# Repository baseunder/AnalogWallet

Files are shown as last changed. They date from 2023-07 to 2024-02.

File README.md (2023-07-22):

# AnalogWallet

## Introduction
Inspired by the online news about a hardware wallet manufacturer that allows private key extraction via closed source firmware i decided to create my own DIY open source crypto wallet.

## Repo
The repository contains the microcontroller source code, 3D STL & Blender files for the case as well as 10MB of random numbers tested with DieHard. Since there is no hardware random number generator on the module I used, i followed the tests of bloc97 
(https://gist.github.com/bloc97/b55f684d17edd8f50df8e918cbc00f94). His 
example uses an analog input with a delay, in my solution I use the 
registers of the Mega32u4 controller to wait for a new ADC conversion. This speeds up the process of generating random numbers a lot.

## Requirements
* Arduino IDE (uECC, EEPROM and SD library)
* Arduino UNO with SD Card reader OR MEGA32u4 SD Card Module (see pictures)
* ISP Programmer (optional and only for production use)
* 3D Printer (optional, for style and electronics protection)

## Crypto
Currently all secp256k1 crypto currencies are supported, this includes for example Bitcoin, Ethereum and of course all Ethereum compatible chains.
The wallet provides plain secp256k1 elliptic curve operations ( https://github.com/kmackay/micro-ecc ):
* Private key generation (random number)
* Public key extraction (on curve)
* Hash signing (for example TX or message signature creation)
* SD Card backup
* SD Card restore

The private key is NEVER stored complete inside the EEPROM or on the SD Card, you always have to provide the correct password to complete the private key. If you enter another password you will end up with another private key that would work too but has no access to your funds.

## Interface
The wallet uses a serial port to communicate with the host system. Inside the py folder you find an example of the protocol used.

## Disclaimer
It should be used only for educational or testing purposes as default 
Arduino boards are not secure by default, their firmware can be updated from the 
computer and this process doesn't require any user interaction. 

## Security
Please upload your sketch with an ISP Programmer and be sure that the Arduino Bootloader is deleted.
Gather your own 10MB of randomness from your device and check the data with some statistic tests (for example https://github.com/nmondal/diehard.c ).
After each "sign" command the device blocks itself and you have to unplug/replug it into your computer.
After each answer from the device there is a 250ms delay inside the communication.

## TODO
Optimize the size of the project so that we can add HMAC-SHA256 key derivation for HD Wallets. Another possible way is to find another USB SD-Card uC board with a bigger flash.
Gather randomness from an Arduino UNO to prove the concept on that platform, this could increase the number of community members.
Generate BTC and ETH addresses from the xpub and make some transactions -> publish the xpub inside this repo so that everyone can try to regenerate the corresponding xpriv (like a bug bounty ;-) ).
User friendly GUI for the communication with the module.

## BadUSB!!
ATTENTION! If you receive such a module DON'T plug it into you Computer because you don't know what program is already loaded inside it. You have to flash the module with an ISP or an ArduinoUNO (Arduino ISP example) the first time. Otherwise the module could act as a virtual Keyboard and harm your privacy or data.

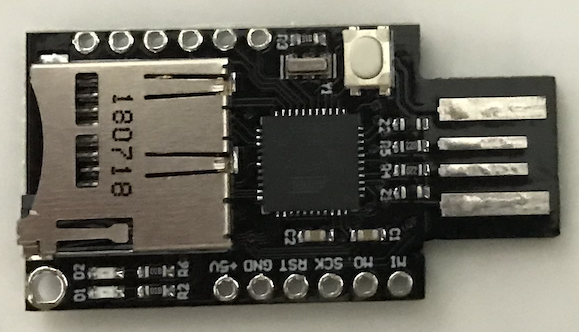
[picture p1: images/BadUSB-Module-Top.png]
BadUSB Module Top

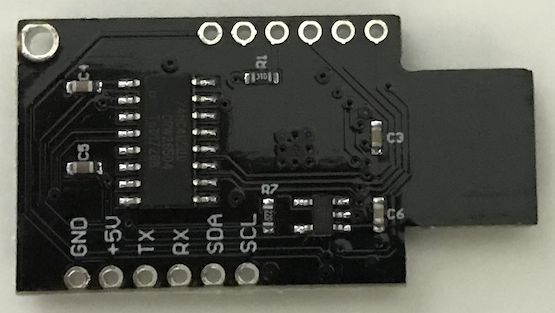
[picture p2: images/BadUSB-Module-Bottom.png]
BadUSB Module Bottom


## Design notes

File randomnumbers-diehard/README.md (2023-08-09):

## Info
For an overview over the "true randomness" topic please visit: https://random.org
## Bad randomness (example)
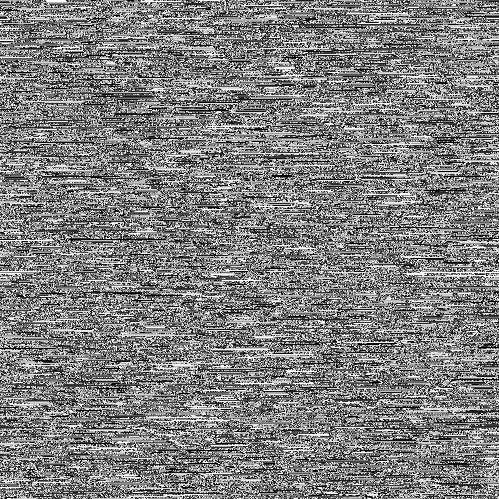
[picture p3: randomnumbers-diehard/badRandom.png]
badRandom randomness picture

## Good randomness (generated with AnalogWallet)
### ATMEGA32U4 Board 1
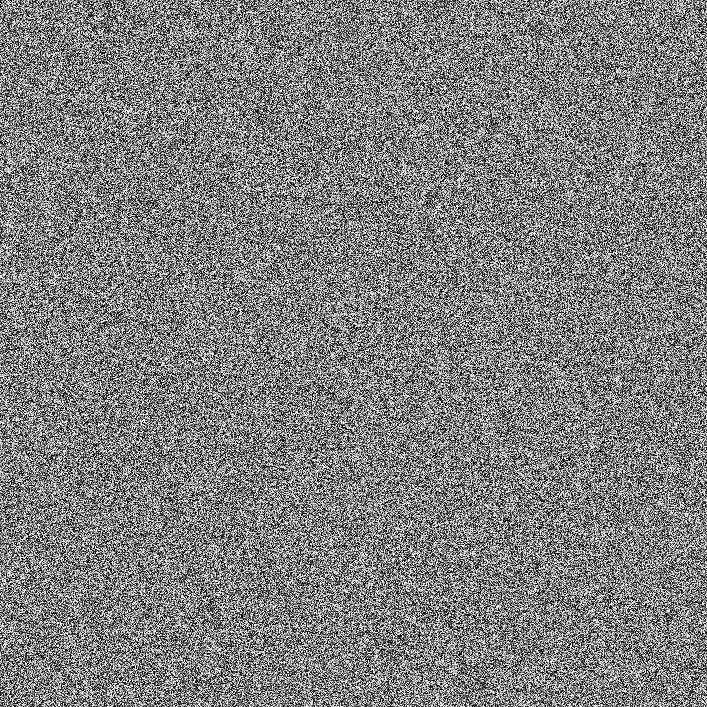
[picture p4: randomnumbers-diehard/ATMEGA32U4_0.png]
ATMEGA32U4_0 randomness picture

### ATMEGA32U4 Board 2
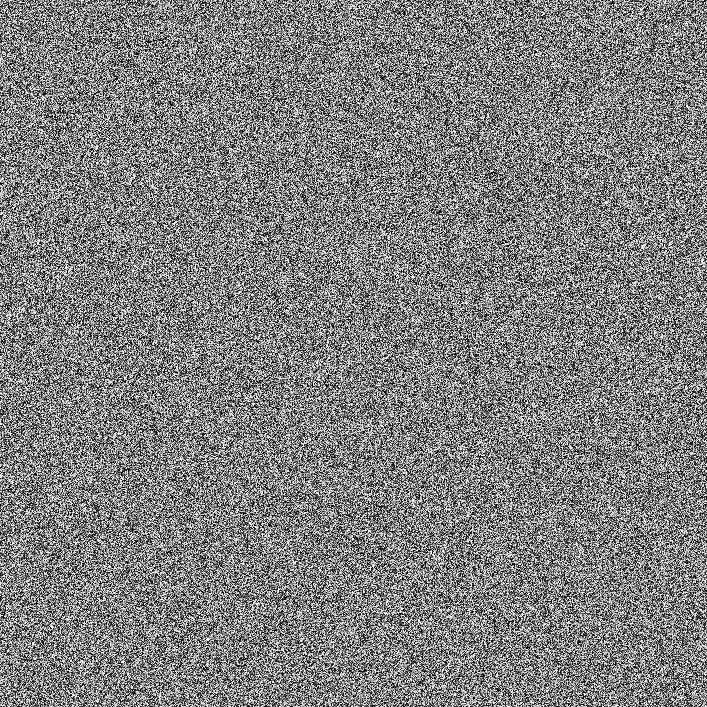
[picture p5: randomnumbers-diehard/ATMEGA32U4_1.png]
ATMEGA32U4_1 randomness picture

### ATMEGA32U4 Board 3
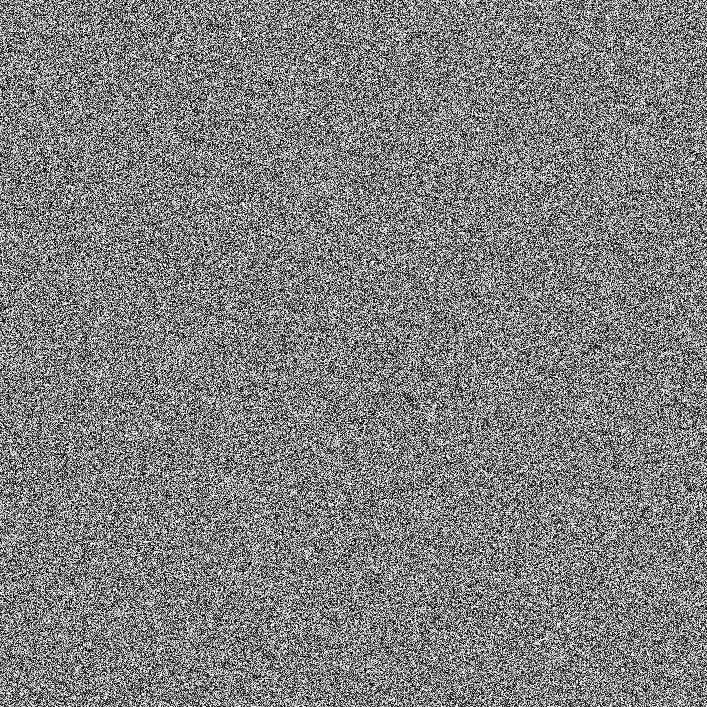
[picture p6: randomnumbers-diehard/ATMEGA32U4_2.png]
ATMEGA32U4_2 randomness picture

### ATMEGA328P Board 1
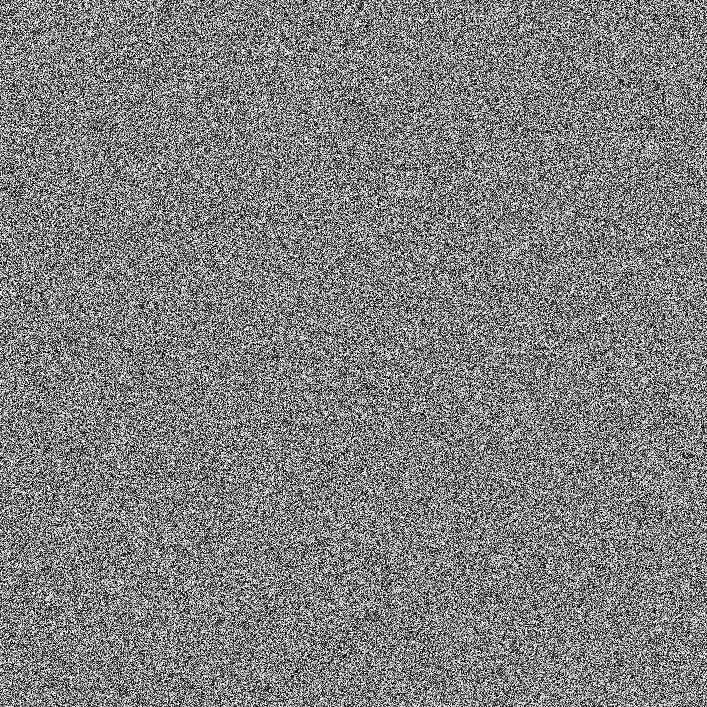
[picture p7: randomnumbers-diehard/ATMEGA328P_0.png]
ATMEGA328P_0 randomness picture


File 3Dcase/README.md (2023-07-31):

# 3D Case

## Introduction
You can protect your wallet by printing a case around your hardware.

## Requirements
* Filament 3D Printer

## How to start
Load the case-Cube.stl into your 3D Slicer, add a PAUSE command just before the top layer begins.
Print the part and wait until the PAUSE is reached, then put your hardware wallet into the semi finisted print.
Now exit the PAUSE and continue with the print. Your printer should now close the wallet inside a solid block of molten plastic.

## How to continue
To make any desired changes, simply open the 'case.blend' file within Blender (downloadable for free at https://www.blender.org/) and modify as needed.

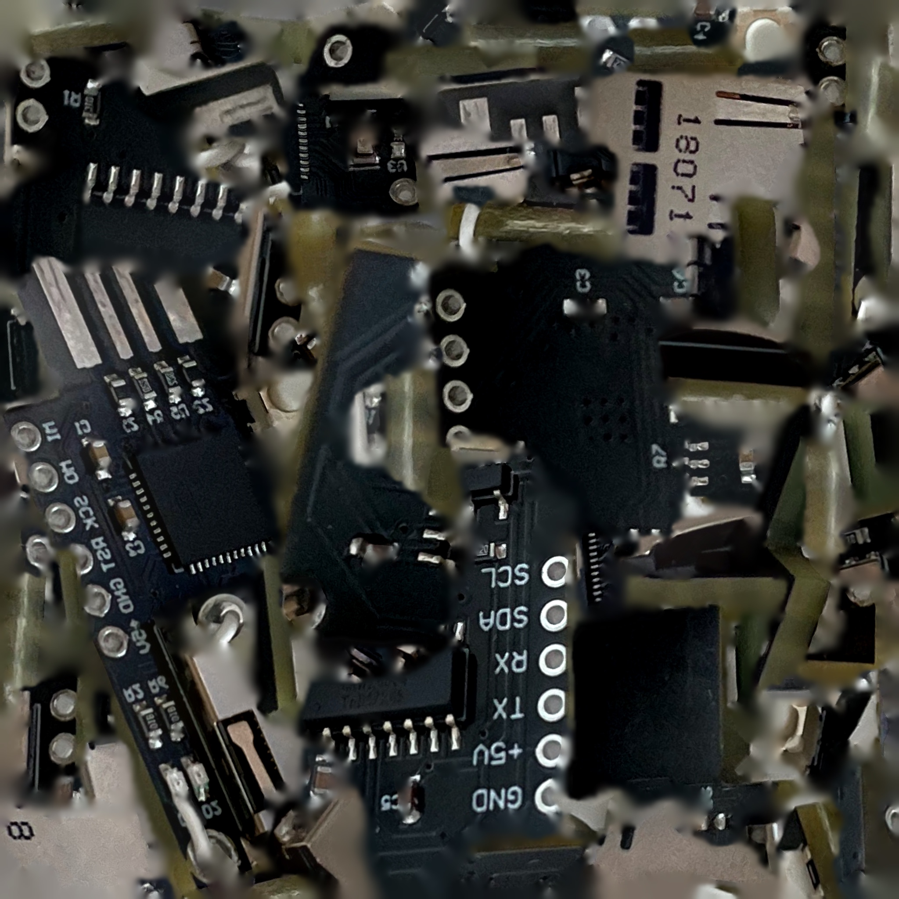
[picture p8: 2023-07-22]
3Dcase/3D-Scan/texgen_0.png

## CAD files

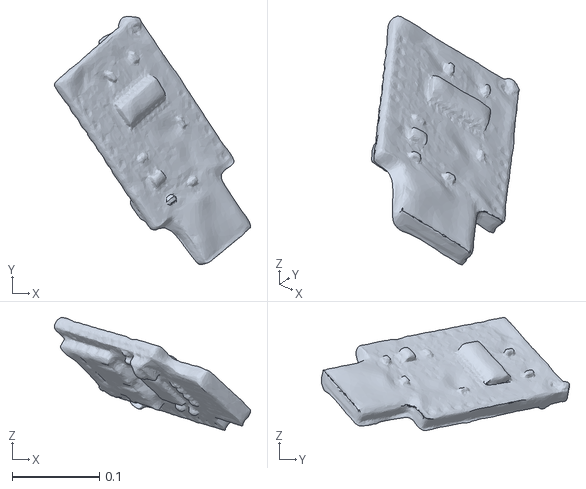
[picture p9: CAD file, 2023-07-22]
3Dcase/3D-Scan/model.obj
0.225 x 0.284 x 0.129

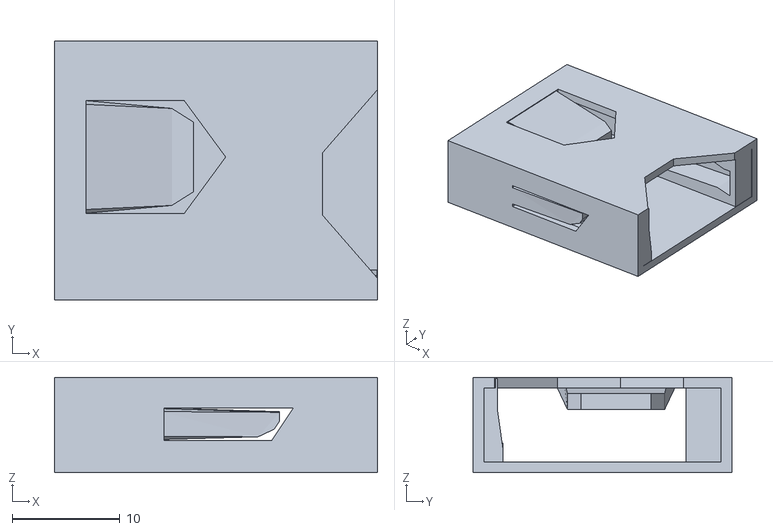
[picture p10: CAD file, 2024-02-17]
3Dcase/ClickCase.stl
30.0 x 24.0 x 8.84

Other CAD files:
3Dcase/ClickCase.blend

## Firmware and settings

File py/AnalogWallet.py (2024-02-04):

import serial
import time
import hashlib
import sys
import os
import ecdsa

from prompt_toolkit import prompt
from serial.tools import list_ports
from pw_check import password_check

class AnalogWallet:
    msgs = {
        0: "DONE",
        1: "Public key:",
        2: "Signature (device blocks after each hash sign action):",
        3: "Backup OK",
        4: "Init done",
        5: "Restore OK",
        6: "Remove SD card",
        7: "Insert SD card",
        8: "Device already initialized, perform erase first if you need reinitialization",
        9: "SD card file write ERROR",
        10: "SD card file read ERROR",
        11: "Backup check ERROR",
        12: "Device not initialized",
        13: "SD card file does not exist",
        14: "SD card backup file created",
        15: "Set filename",
        16: "This may take up to 30 seconds, please be patient... Hash to sign:",
        17: "Signing failed",
        18: "Device ID and card status:",
        19: "Firmware hash:",
        20: "Try signing...",
        21: "Device is blocked until reconnect"
    }

    @staticmethod
    def verify(pubkString, hashString, signatureString):
        class dummyHash:
            def __init__(self, hash) -> None:
                self.hash = hash

            def digest(self):
                return self.hash
        pub_key_bytes = bytes.fromhex(pubkString)
        hsh = bytes.fromhex(hashString)
        sig_bytes = bytes.fromhex(signatureString)
        vk = ecdsa.VerifyingKey.from_string(pub_key_bytes, curve=ecdsa.SECP256k1)
        veri = ecdsa.VerifyingKey.verify(vk, sig_bytes, hsh, hashfunc=dummyHash)
        return veri

    @staticmethod
    def getPasswordBytes():
        password = prompt("Enter password/secret: ", is_password=True)
        #if not password_check(password):
        #    return None
        passwordbytes = hashlib.sha256(password.encode()).digest()
        return passwordbytes        
    def waitForDisconnect(self):
        ports = list_ports.comports()
        print("disconnect your wallet now")
        while True:
            newports = list_ports.comports()
            if len(ports)>len(newports):
                return
            time.sleep(0.5)

    def __init__(self, showCommands=False):
        global WALLET
        self.ser = None
        port = AnalogWallet.waitForConnect()
        time.sleep(0.5)
        self.ser = serial.Serial(port, 115200)
        self.commands = ['init', 'open', 'erase', 'sign', 'restore', 'rnd', 'getid', 'firmwarehash']
        self.chaincommands = ['ether']
        self.commands += self.chaincommands
        if showCommands:
            print("-".join([" " for _ in range(10)]))
            print("\n".join(self.commands))
            print("-".join([" " for _ in range(10)]))
        self.deviceOpen = False
        self.PUBLIC_KEY = None
        self.HASH_TO_SIGN = None
        self.SIGNATURE = None
        self.PASSWORD = None
        self.HEXHASH = None
        self.ID = None
        WALLET = self

    def guide(self):
        command = prompt("Enter command: ")
        if not (command in self.commands):
            if command == "exit":
                print("AnalogWallet session ends now...")
                return
            else:
                print("command", command, "not found")
                return
        if command in self.chaincommands:
            if self.deviceOpen:
                from chains.ethereum import ETHtx
                ETHtx(self.PUBLIC_KEY, self.ser, self.msgs)
                return
            else:
                print("Wallet is not open")
                return
        self.run(command)
    
    def write(self, data):
        self.ser.write(data)
        self.ser.flush()
        while self.ser.out_waiting:
            time.sleep(0.01)

    def run(self, command):
        cmIndex = self.commands.index(command).to_bytes(1, "little")
        print("run", command)
        if command in {"open", "firmwarehash"}:
            if self.PASSWORD is None:
                self.PASSWORD = self.getPasswordBytes()
                if not self.PASSWORD:
                    return
            self.write(cmIndex)
            self.write(self.PASSWORD)
        elif command in {"init"}:
            if self.PASSWORD is None:
                self.PASSWORD = self.getPasswordBytes()
                if not self.PASSWORD:
                    return
            if self.ID is None:
                self.ID = hashlib.sha256(str(time.time()).encode()).digest()
            self.write(cmIndex)
            self.write(self.PASSWORD)
            self.write(self.ID)
        elif command == "sign":
            if self.HEXHASH is None:
                self.HEXHASH = prompt("Enter hash [HEX]: ")
                self.HEXHASH = bytes.fromhex(self.HEXHASH)
                if len(self.HEXHASH) != 32:
                    print("hash not valid")
                    return
            self.write(cmIndex)
            self.write(self.HEXHASH)
        elif command == "restore":
            print(
                "The device blocks after the backup is done, you have to replug it to continue.")
            self.write(cmIndex)
        elif command == "erase":
            self.write(cmIndex)
        elif command == "rnd":
            ofname = input("provide a filename for your random data:")
            if os.path.exists(ofname):
                print("this file does already exist...")
                exit()
            output_file = open(ofname, 'wb')
            self.write(cmIndex)
            endsize = int(10000000/256)  # 10MB
            count = 0
            try:
                while True:
                    received_data = self.ser.read(256)
                    if len(received_data) < 256:
                        raise KeyboardInterrupt
                    output_file.write(received_data)
                    print("size:", count*256, "sample:", int(received_data.hex()[:2], 16), int(
                        received_data.hex()[2:4], 16), int(received_data.hex()[4:6], 16))
                    count += 1
                    if count > endsize:
                        raise KeyboardInterrupt
            except KeyboardInterrupt:
                output_file.close()
            print("your random data is now generated:", output_file)
        elif command == "getid":
            self.write(cmIndex)
        return command

    def parseResponses(self, command):
        while True:
            while not self.ser.in_waiting:
                time.sleep(0.05)
            fis = int.from_bytes(self.ser.read(), "little")
            if fis in self.msgs.keys():
                print(self.msgs[fis])
                if fis == 1:
                    while not self.ser.in_waiting:
                        time.sleep(0.05)
                    fis = self.ser.read(64)
                    print(fis.hex())
                    self.PUBLIC_KEY = fis.hex()
                    self.deviceOpen = True
                elif fis == 2:
                    while not self.ser.in_waiting:
                        time.sleep(0.05)
                    fis = self.ser.read(64)
                    print(fis.hex())
                    self.SIGNATURE = fis.hex()
                    assert self.verify(self.PUBLIC_KEY, self.HASH_TO_SIGN, self.SIGNATURE)
                    print(
                        "SIGNATURE TEST OK:\nsignature created by the private key is verified with the public key")
                elif fis == 6 or fis == 7:
                    self.waitForDisconnect()
                    exit()
                elif fis == 16:
                    while not self.ser.in_waiting:
                        time.sleep(0.05)
                    fis = self.ser.read(32)
                    print(fis.hex())
                    self.HASH_TO_SIGN = fis.hex()
                elif fis == 14 or fis == 15:
                    while not self.ser.in_waiting:
                        time.sleep(0.05)
                    fis = self.ser.read(8)
                    print(fis)
                elif fis == 18:
                    while not self.ser.in_waiting:
                        time.sleep(0.05)
                    fis = self.ser.read(32)
                    print(fis.hex())
                    fis = self.ser.read(1)
                    print(fis.hex())
                elif fis == 19:
                    while not self.ser.in_waiting:
                        time.sleep(0.05)
                    fis = self.ser.read(32)
                    print(fis.hex())
                elif fis == 20:
                    pass
                elif fis == 21:
                    self.waitForDisconnect()
                else:
                    if command == "init":
                        print("Unplug the device and remove the SD card now, store the backup SD card in a secure place, it is the only possibility to restore your wallet.")
                        print("Write down your password, a restore of the wallet with your SD card is only possible if you have the right password.")
                    break
            else:
                print(fis)
    @staticmethod
    def waitForConnect():
        ports = list_ports.comports()
        print("connect your wallet now")
        while True:
            newports = list_ports.comports()
            if len(ports)<len(newports):
                return list(set(newports).symmetric_difference(set(ports)))[0].device
            time.sleep(0.5)

if __name__ == "__main__":
    if "test" in sys.argv:
        cmds = ["erase", "firmwarehash", "init", "reconnect", "getid", "open", "sign", "reconnect", "erase", "restore", "reconnect", "open"]
        aw = AnalogWallet()
        aw.PASSWORD = hashlib.sha256("12345".encode()).digest()
        aw.HEXHASH = hashlib.sha256("test".encode()).digest()
        for cmd in cmds:
            if cmd == "reconnect":
                aw.waitForDisconnect()
                aw = AnalogWallet()
                aw.PASSWORD = hashlib.sha256("12345".encode()).digest()
                aw.HEXHASH = hashlib.sha256("test".encode()).digest()
            else:
                print("send",cmd)
                aw.run(cmd)
                aw.parseResponses(cmd)
    else:
        aw = AnalogWallet(True)
        while True:
            cmd = aw.guide()
            aw.parseResponses(cmd)

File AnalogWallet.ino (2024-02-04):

#include "random.h"
#include "wallet.h"
#include "integrity.h"
uint8_t sbuffer[32] = {0};

void waitForSerial(){
  while (!Serial.available()){getTrueRotateRandomByteWithSHAupdate();}
}

void setup()
{
  setRNG();
  Serial.begin(115200);
  while (!Serial){getTrueRotateRandomByteWithSHAupdate();}
}

void stayBlocked(){
  while(1){
    waitForSerial();
    Serial.write((uint8_t)21);
  }
}

void loop()
{
  waitForSerial();
  int cmd = Serial.read();
  if (cmd==0){ // init
      waitForSerial();
      Serial.readBytes(sbuffer, 32);
      Serial.write(initDevice(sbuffer));
      stayBlocked();
  }
  if (cmd==1){ // open
      waitForSerial();
      Serial.readBytes(sbuffer, 32);
      Serial.write(walletstart(sbuffer, false));
  }
  if (cmd==2){ // erase
      eraseDevice();
      Serial.write((uint8_t)0);
  }
  if (cmd==3){ // sign
      waitForSerial();
      Serial.readBytes(sbuffer, 32);
      Serial.write(sign(sbuffer));
      stayBlocked();
  }
  if (cmd==4){ // restore
      Serial.write(restore());
      stayBlocked();
  }
  if (cmd==5){ // rnd
      while (1)
      {
        Serial.write(getTrueRotateRandomByte());
      }
  }
  if (cmd==6){ // get id and card status
      writeStatus();
  }
  if (cmd==7){ // get firmware integrity hash
    waitForSerial();
    Serial.readBytes(sbuffer, 32);
    getIntegrityHash(sbuffer);
  }
  delay(250);
}

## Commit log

2023-07-20 add 3D files for the case
    [case-Top.stl, case.blend]
2023-07-20 add random data from 3 devices
2023-07-22 add 3D scan of module
    [model.obj]
2023-07-24 add arduino UNO randomness, rename random data files to microcontroller name
2023-07-29 improve protocol, solve backup bug
    [AnalogWallet.ino, bckp.cpp, main.py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]
2023-07-31 update 3D case for printing
    [case-Cube.stl, case-Top.stl, case.blend]
2023-07-31 add new 3D case
    [case-Cube.stl, case.blend]
2023-07-31 add 3D case readme file
2023-07-31 add arduino uno random picture
2023-08-08 disable LED blinking during flickr test
2023-10-30 add status and device id
2023-11-22 add small footprint SD card communication for the backup
2023-12-08 add new 3D print case
    [ClickCase.stl]
2024-02-17 add new case and more entropy rounds
    [ClickCase.blend, ClickCase.stl, case-Cube.stl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]
